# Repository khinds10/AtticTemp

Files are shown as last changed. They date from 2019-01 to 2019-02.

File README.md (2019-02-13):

# AtticTemp - temperature / climate logger
High tolerance temperature gauge and climate logger for your attic or other outdoor structures

#### Flashing RaspberriPi Hard Disk / Install Required Software (Using Ubuntu Linux)

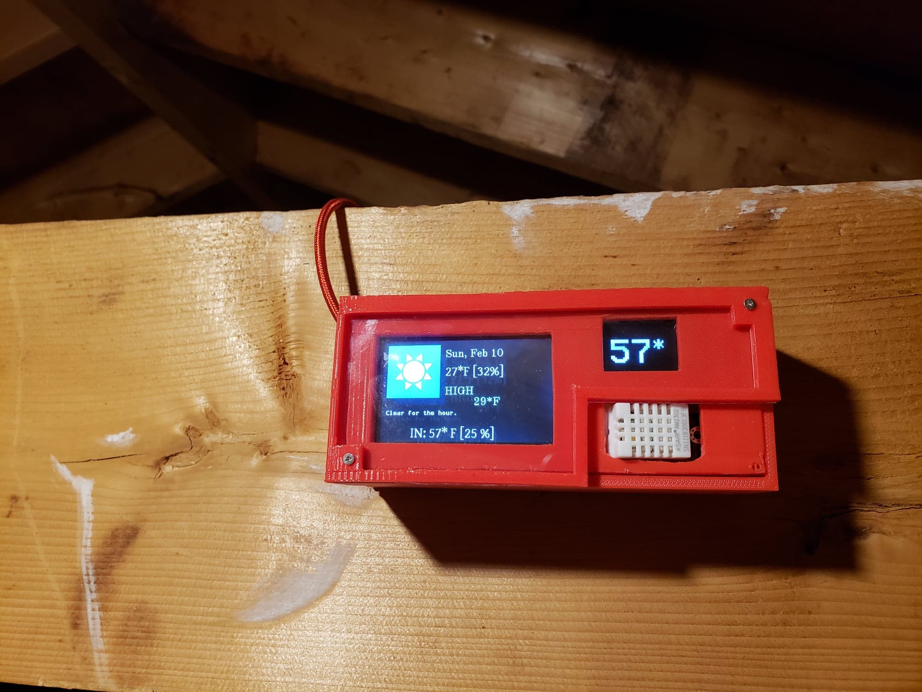
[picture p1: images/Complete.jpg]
Completed


Download "RASPBIAN JESSIE LITE"
https://www.raspberrypi.org/downloads/raspbian/

**Create your new hard disk for DashboardPI**
>Insert the microSD to your computer via USB adapter and create the disk image using the `dd` command
>
> Locate your inserted microSD card via the `df -h` command, unmount it and create the disk image with the disk copy `dd` command
>
> $ `df -h`
> */dev/sdb1       7.4G   32K  7.4G   1% /media/XXX/1234-5678*
>
> $ `umount /dev/sdb1`
>
> **Caution: be sure the command is completely accurate, you can damage other disks with this command**
>
> *if=location of RASPBIAN JESSIE LITE image file*
> *of=location of your microSD card*
>
> $ `sudo dd bs=4M if=/path/to/raspbian-jessie-lite.img of=/dev/sdb`
> *(note: in this case, it's /dev/sdb, /dev/sdb1 was an existing factory partition on the microSD)*

**Setting up your RaspberriPi**

*Insert your new microSD card to the raspberrypi and power it on with a monitor connected to the HDMI port*

Login
> user: **pi**
> pass: **raspberry**

Change your account password for security
>`sudo passwd pi`

Enable RaspberriPi Advanced Options
>`sudo raspi-config`

Choose:
`1 Expand File System`

`9 Advanced Options`
>`A2 Hostname`
>*change it to "AtticTemp"*
>
>`A4 SSH`
>*Enable SSH Server*
>
>`A7 I2C`
>*Enable i2c interface*

**Enable the English/US Keyboard**

>`sudo nano /etc/default/keyboard`

> Change the following line:
>`XKBLAYOUT="us"`

**Reboot PI for Keyboard layout changes / file system resizing to take effect**
>$ `sudo shutdown -r now`

**Auto-Connect to your WiFi**

>`sudo nano /etc/wpa_supplicant/wpa_supplicant.conf`

Add the following lines to have your raspberrypi automatically connect to your home WiFi
*(if your wireless network is named "linksys" for example, in the following example)*

	network={
	   ssid="linksys"
	   psk="WIRELESS PASSWORD HERE"
	}

**Reboot PI to connect to WiFi network**

>$ `sudo shutdown -r now`
>
>Now that your PI is finally on the local network, you can login remotely to it via SSH.
>But first you need to get the IP address it currently has.
>
>$ `ifconfig`
>*Look for "inet addr: 192.168.XXX.XXX" in the following command's output for your PI's IP Address*

**Go to another machine and login to your raspberrypi via ssh**

> $ `ssh pi@192.168.XXX.XXX`

**Start Installing required packages**

>$ `sudo apt-get update`
>
>$ `sudo apt-get upgrade`
>
>$ `sudo apt-get install vim git python-requests python-smbus i2c-tools python-imaging python-smbus build-essential python-dev rpi.gpio python3 python3-pip libi2c-dev`

**Update local timezone settings**

>$ `sudo dpkg-reconfigure tzdata`

> select your timezone using the interface

**Setup the simple directory `l` command [optional]**

>$ `vi ~/.bashrc`
>
>*add the following line:*
>
>$ `alias l='ls -lh'`
>
>$ `source ~/.bashrc`

**Fix VIM default syntax highlighting [optional]**

>$ `sudo vi /etc/vim/vimrc`
>
>uncomment the following line:
>
>_syntax on_

**Clone Project repository**

>$ `cd ~`
>
>$ `git clone https://github.com/khinds10/AtticTemp.git`

**DHT22 Install**

>$ `cd ~`
>
>$ `git clone https://github.com/adafruit/Adafruit_Python_DHT.git`
>
>$ `cd Adafruit_Python_DHT/`
>
>$ `sudo python setup.py install`
>
>$ `sudo python ez_setup.py`
>
>$ `cd examples/`
>
>$ `vi simpletest.py`
>

Change the following line:
> sensor = Adafruit_DHT.DHT22

Comment the line out
> pin = 'P8_11'

Uncomment the line and change the pin number to 16
> pin = 18

Run the test

`python simpletest.py`

> You should see a metric reading of Temp and Humidity displayed on the command line.

**SSD1306 Install**

Extract drivers/SSD1306.zip to the project folder

Install the Driver

> cd ssd1306/
>$ sudo python setup.py install

Confirm your device registers, usually it's \0x3c on the i2c bus

>$ sudo i2cdetect -y 1

         0  1  2  3  4  5  6  7  8  9  a  b  c  d  e  f
    00:          -- -- -- -- -- -- -- -- -- -- -- -- -- 
    10: -- -- -- -- -- -- -- -- -- -- -- -- -- -- -- -- 
    20: -- -- -- -- -- -- -- -- -- -- -- -- -- -- -- -- 
    30: -- -- -- -- -- -- -- -- -- -- -- -- 3c -- -- -- 
    40: -- -- -- -- -- -- -- -- -- -- -- -- -- -- -- -- 
    50: -- -- -- -- -- -- -- -- -- -- -- -- -- -- -- -- 
    60: -- -- -- -- -- -- -- -- -- -- -- -- -- -- -- -- 
    70: -- -- -- -- -- -- -- --

Run the demo to confirm your display is in working order

>$ cd examples/
>$ python demo.py 

## Supplies Needed

RaspberriPi Zero

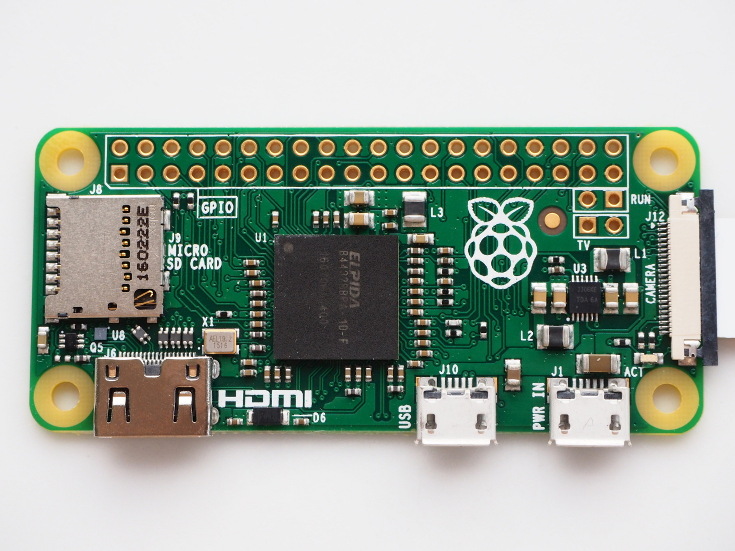
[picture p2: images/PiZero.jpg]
RaspberriPi Zero


DHT22 temperature-humidity sensor

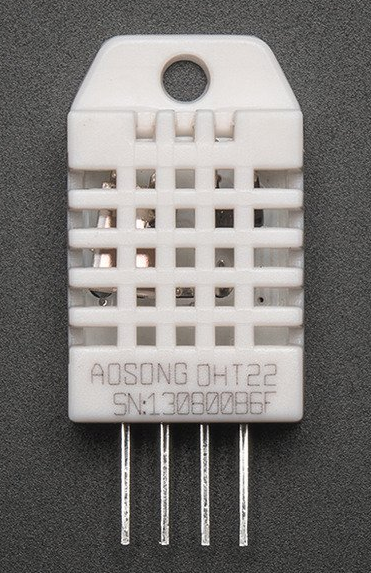
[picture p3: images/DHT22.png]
DHT22


0.96" I2C IIC SPI Serial 12864 OLED LCD LED White Display Module 

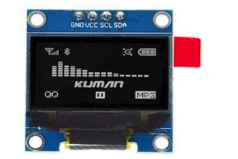
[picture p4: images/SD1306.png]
SD1306


2.4" 400x240 16:9 Serial:UART/I2C/SPI TFT Touchscreen Display 

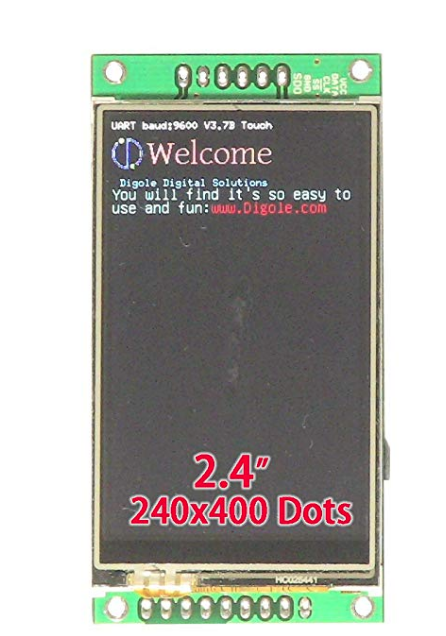
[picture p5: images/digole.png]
Digole Display


## Wire the device

**SSD1306 Display**

> GND -> GND
>
> DATA -> SDA
>
> CLK -> SCL
>
> VCC -> 3V

**Digole Display**

> GND -> GND
>
> DATA -> SDA
>
> CLK -> SCL
>
> VCC -> 3V

**DHT22 Humidistat**

> VCC -> 5V
>
> GND -> GND
>
> DATA -> GPIO 18 / PIN 12
>

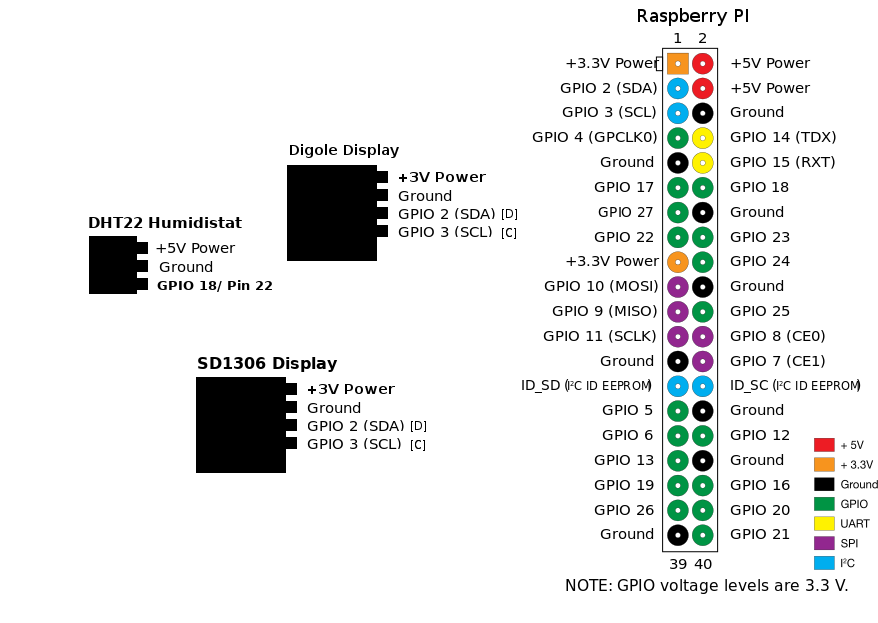
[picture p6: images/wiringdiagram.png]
Pi Wiring Diagram


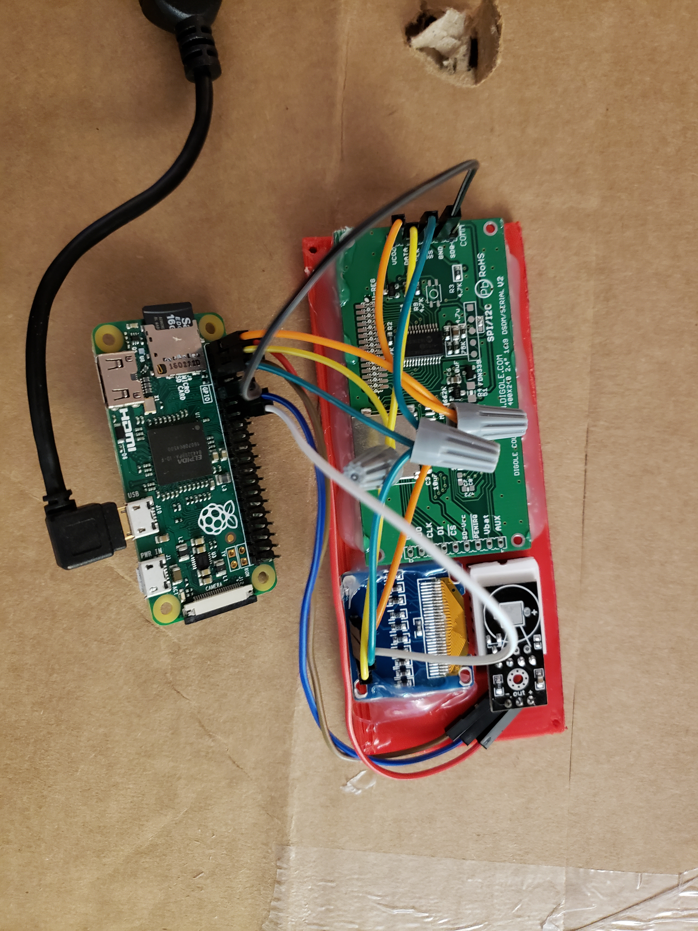
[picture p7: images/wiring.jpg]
Pi Wiring


## Build the device

Cut Plexiglass to fit the front of the device under the 3D printed frame

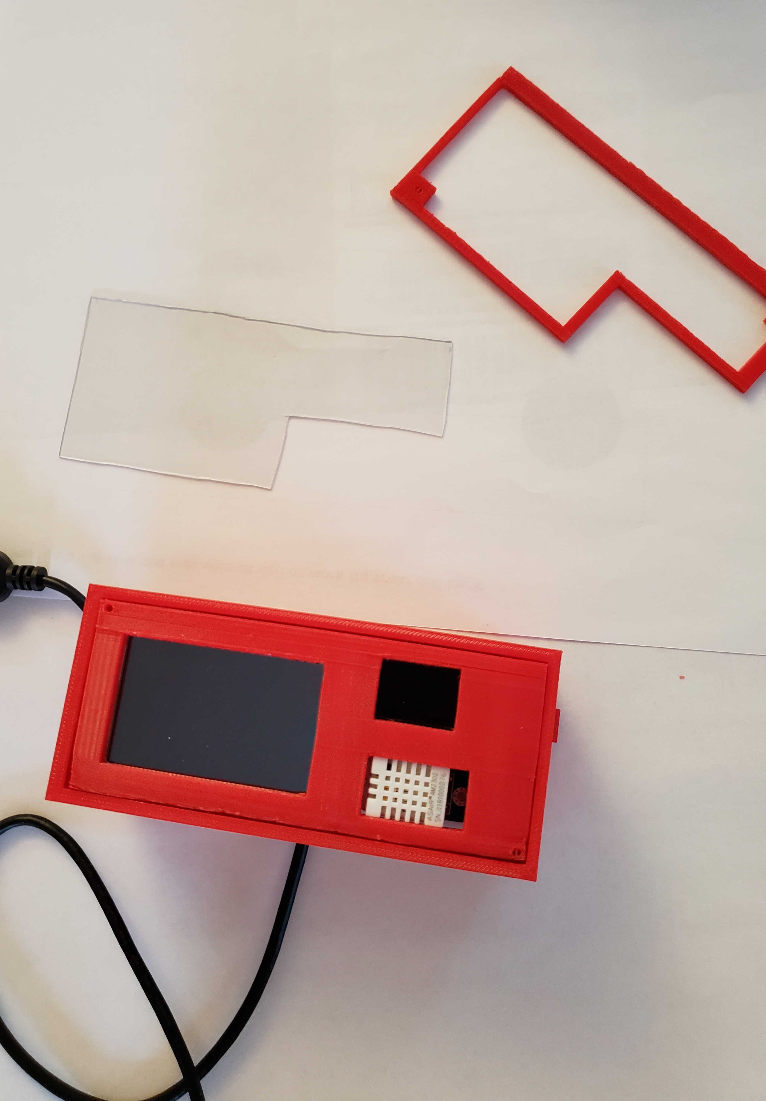
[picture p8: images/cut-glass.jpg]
Cut Plexiglass


Mount the glass with screws through the 3D printed frame

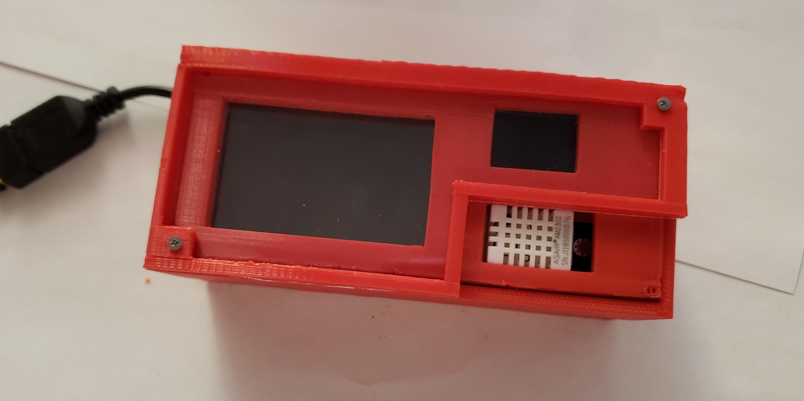
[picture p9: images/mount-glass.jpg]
Mount Glass


Hot Glue Components against the front panel

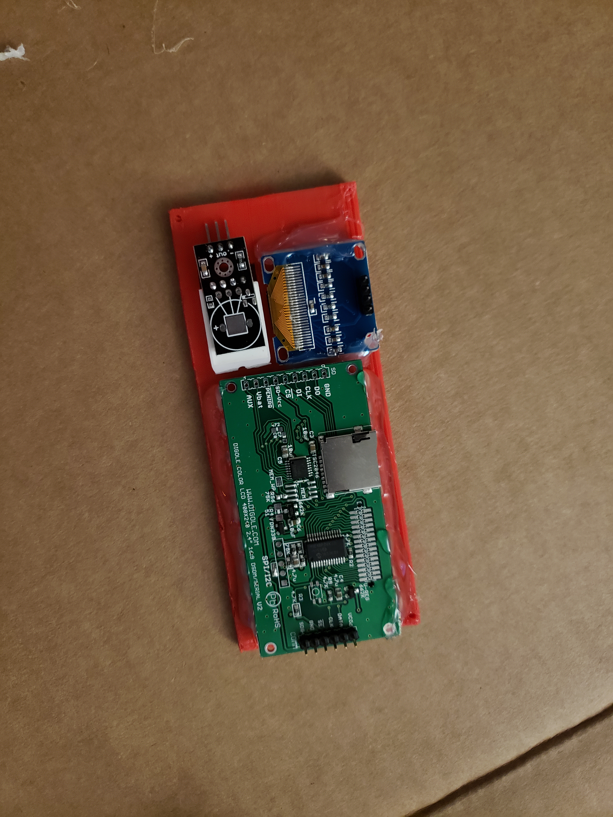
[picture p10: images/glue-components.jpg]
Hot Glue


Wire Unit inside

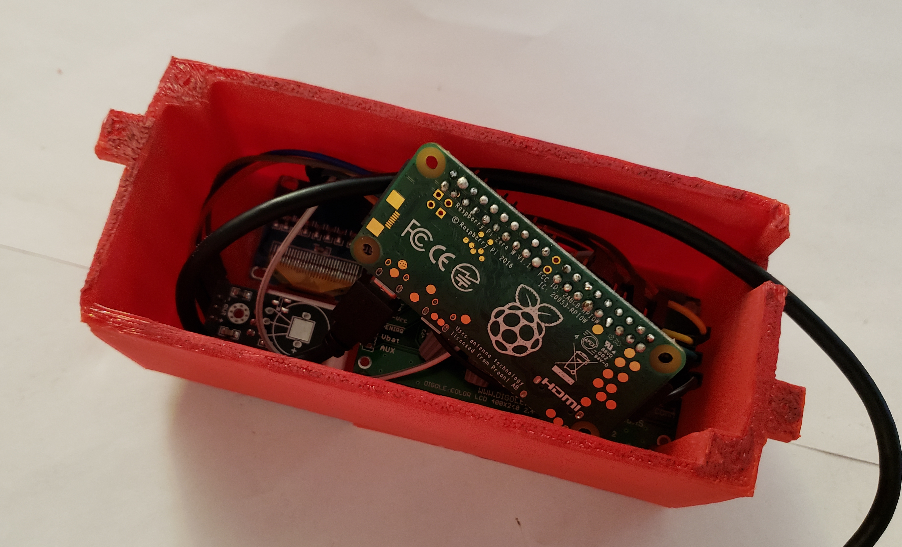
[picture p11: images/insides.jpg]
Inside Unit


Mount the back and it should be ready to go

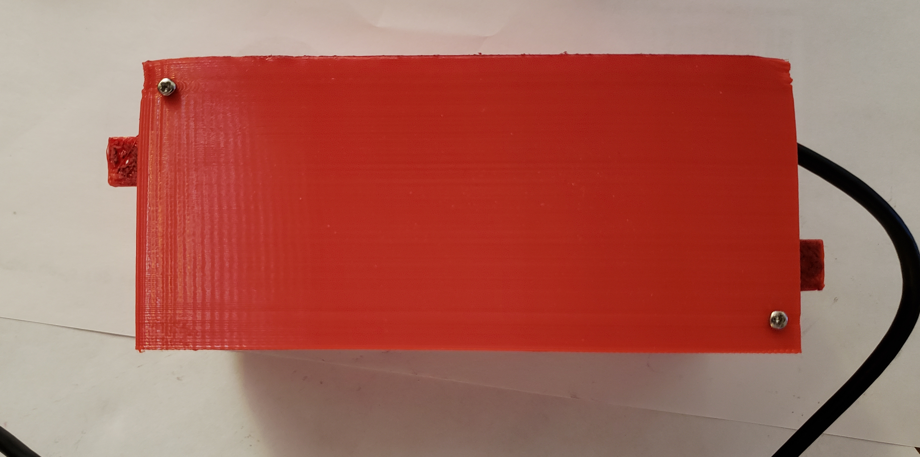
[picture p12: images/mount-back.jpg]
Mount Back


## Configure Application to run correctly in settings.py config file

Find the file `settings.py` and adjust to your current settings

> \# forecast.io API key for local weather information
>
> weatherAPIURL = 'https://api.forecast.io/forecast/'
>
> weatherAPIKey = 'YOUR API KEY FOR FORECAST.IO'
> 
> \# optional for running the remote temp/humidity logger
>
> deviceLoggerAPI = 'mydevicelogger.com'
>
> \# search google to get the Latitude/Longitude for your home location
>
> latitude = 41.4552578
>
> longitude = -72.1665444
>

## Setup Scheduled Scripts

>$ `crontab -e`

Add the following lines:

`*/7 * * * * python /home/pi/AtticTemp/displays.py`

## OPTIONAL: Temp Logger to API script each 10 minutes

>$ `crontab -e`

Add the following lines:

`*/10 * * * * python /home/pi/EnvironmentClock/temp-check.py`

## OPTIONAL: Creating your own weather images to render on the display

Upload your own 128x128 file to the following URL:

http://www.digole.com/tools/PicturetoC_Hex_converter.php 

Choose your image file to upload, add what size you want it to be on the screen (Width/Height)

Select "256 Color for Color OLED/LCD(1 byte/pixel)" in the "Used for" dropdown

Obtain the hex output.

Add the hex output to a display/build/ header (.h) file, use the other ones as guides for syntax.

Include the new file in the digole.c file 
`#include "myimage.h`

Include a new command line hook to your image file in the.
_Note: the command below is saying draw your image at position 10 pixels over 10  pixels down. You can change it to different X,Y coordinates, you can also change the values 128,128 to whatever size your new image actually is._

`} else if (strcmp(digoleCommand, "myimage") == 0) {`
    `drawBitmap256(10, 10, 128, 128, &myimageVariableHere,0);  // myimageVariableHere is defined in your (.h) file`
`}`

Now rebuild (ignore the errors) below to have your new image render with the following command.
>$ `./digole myimage`

**Re-Building [Included] Digole Display Driver for your optional changes**

>$ `cd display/build`

>$ `gcc digole.c`

>$ `mv a.out ../../digole`

>$ `chmod +x ../../digole`

# FINISHED!

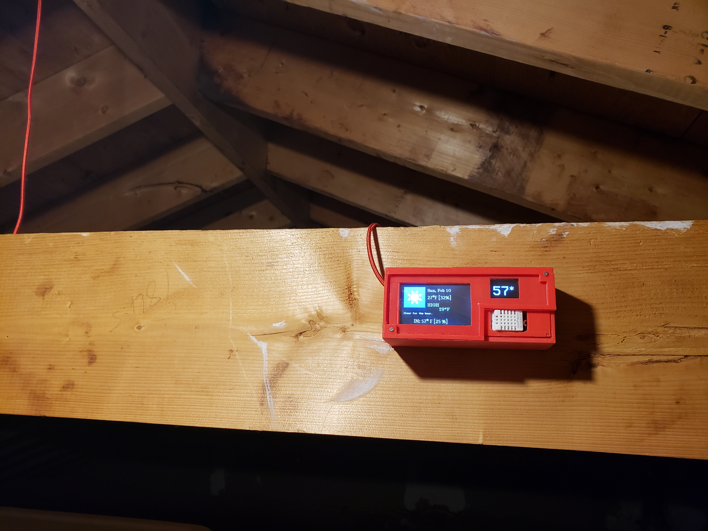
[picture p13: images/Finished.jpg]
Finished


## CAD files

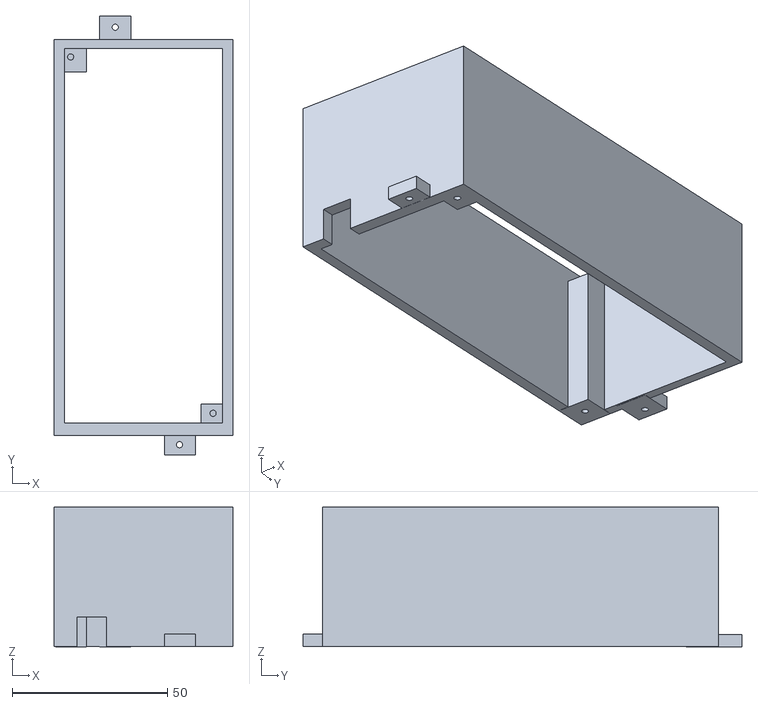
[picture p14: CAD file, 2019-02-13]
enclosure/main-box.stl
57.5 x 141.4 x 45.1

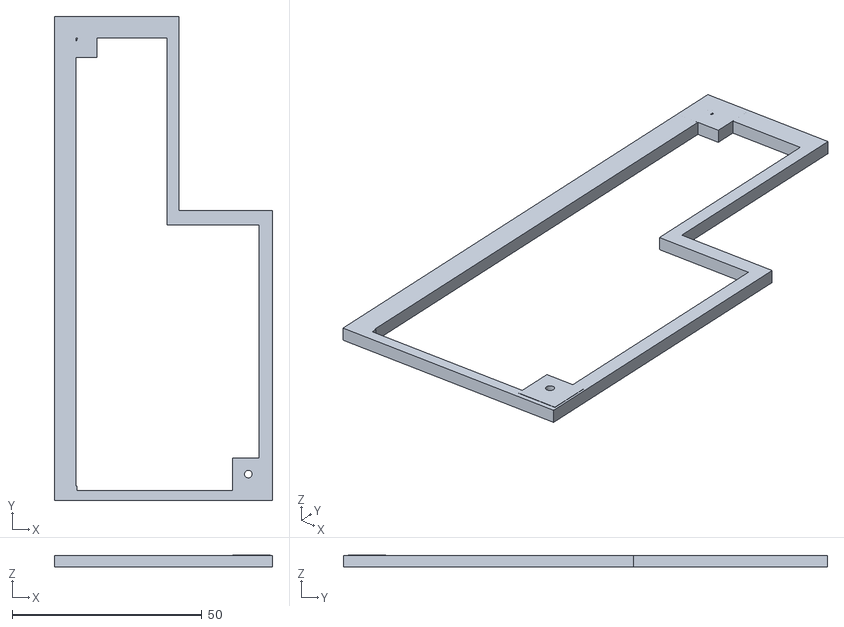
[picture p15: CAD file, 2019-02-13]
enclosure/glass-panel.stl
57.5 x 127.5 x 3.07

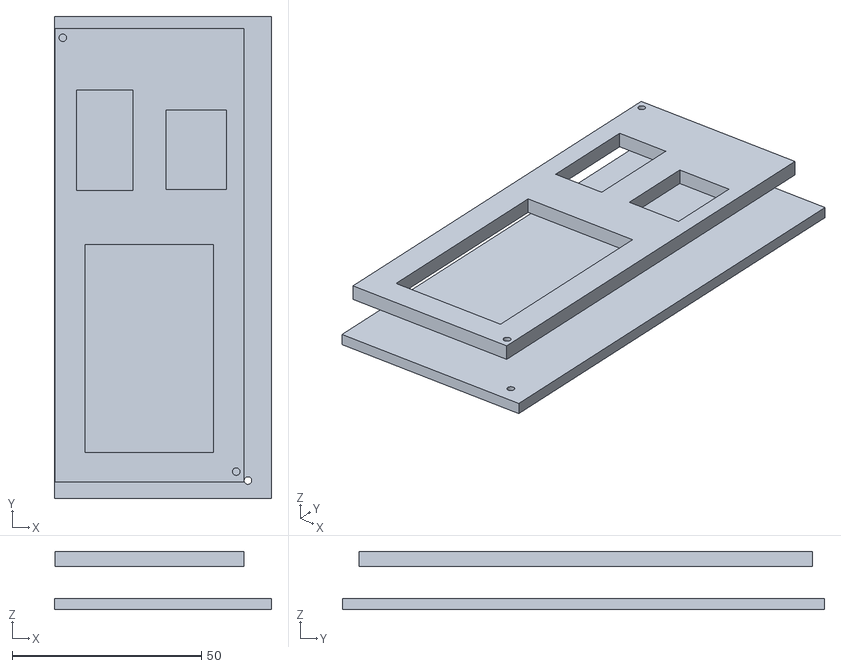
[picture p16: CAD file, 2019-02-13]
enclosure/top-bottom.stl
57.5 x 127.5 x 15.4

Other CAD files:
enclosure/enclosure-final.blend
enclosure/enclosure.blend

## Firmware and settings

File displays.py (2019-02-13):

#!/usr/bin/python
# Kevin Hinds http://www.kevinhinds.com
# License: GPL 2.0
import datetime as dt
import time, json, string, cgi, subprocess, json
import settings as settings
import Adafruit_DHT
from oled.device import ssd1306
from oled.render import canvas
from PIL import ImageFont

# mono 8 bit font
font = ImageFont.truetype('/home/pi/AtticTemp/fonts/vcr.ttf', 50)
device = ssd1306(port=1, address=0x3C)

## Raspberry Pi with DHT22 sensor - connected to GPIO18 / Pin 12
sensor = Adafruit_DHT.DHT22
pin = 18

# get current date and time
date=dt.datetime.now()

# get 10 readings and average, in case the humidistat is inaccurate
count, readingCount, avgTemperature, avgHumidity = [ 0, 0, 0, 0 ]
while (count < 10):    
    humidity, temperature = Adafruit_DHT.read_retry(sensor, pin)
    if humidity is not None and temperature is not None:
        avgTemperature = avgTemperature + temperature
        avgHumidity = avgHumidity + humidity
        readingCount = readingCount + 1                
    count = count + 1
avgTemperature = avgTemperature / readingCount
insideTemperature = int(avgTemperature * 9/5 + 32)
avgHumidity = avgHumidity / readingCount
insideHumidity = int(avgHumidity)

# show temp on the 1306 display
with canvas(device) as draw:
    if insideTemperature > 100:
        font = ImageFont.truetype('/home/pi/AtticTemp/fonts/vcr.ttf', 50)
        draw.text((0, 10),    str(insideTemperature),  font=font, fill=255)
        font = ImageFont.truetype('/home/pi/AtticTemp/fonts/vcr.ttf', 30)
        draw.text((90, 15),    str("*"),  font=font, fill=255)
    elif insideTemperature >= 0:
        font = ImageFont.truetype('/home/pi/AtticTemp/fonts/vcr.ttf', 60)
        draw.text((0, 10),    str(insideTemperature),  font=font, fill=255)
        font = ImageFont.truetype('/home/pi/AtticTemp/fonts/vcr.ttf', 40)
        draw.text((70, 15),    str("*"),  font=font, fill=255)       
    else:
        font = ImageFont.truetype('/home/pi/AtticTemp/fonts/vcr.ttf', 50)
        draw.text((0, 10),    str(insideTemperature),  font=font, fill=255)
        font = ImageFont.truetype('/home/pi/AtticTemp/fonts/vcr.ttf', 30)
        draw.text((90, 15),    str("*"),  font=font, fill=255)

# get current forecast from location
weatherInfo = json.loads(subprocess.check_output(['curl', settings.weatherAPIURL]))
currentConditions = weatherInfo['currently']
icon = str(currentConditions['icon'])
apparentTemperature = str(int(currentConditions['apparentTemperature']))
humidity = str(int(currentConditions['humidity'] * 100))
windSpeed = str(int(currentConditions['windSpeed']))
cloudCover = str(int(currentConditions['cloudCover'] * 100))
precipProbability = str(int(currentConditions['precipProbability'] * 100))

# minutely conditions, limit the characters to 30 in the summary
minutelyConditions = weatherInfo['minutely']
summary = str(minutelyConditions['summary'])
summary = (summary[:27] + '...') if len(summary) > 29 else summary

# conditions for the day
dailyConditions = weatherInfo['daily']
dailyConditions = dailyConditions['data'][0]
apparentTemperatureMin = str(int(dailyConditions['apparentTemperatureMin']))
apparentTemperatureMax = str(int(dailyConditions['apparentTemperatureMax']))

# clear and setup display to show basic info
subprocess.call(["/home/pi/AtticTemp/digole", "clear"])
subprocess.call(["/home/pi/AtticTemp/digole", "setRot90"])
subprocess.call(["/home/pi/AtticTemp/digole", icon])
subprocess.call(["/home/pi/AtticTemp/digole", "setFont", "18"])
subprocess.call(["/home/pi/AtticTemp/digole", "setColor", "255"])
subprocess.call(["/home/pi/AtticTemp/digole", "printxy_abs", "10", "178", summary])
subprocess.call(["/home/pi/AtticTemp/digole", "setFont", "51"])
subprocess.call(["/home/pi/AtticTemp/digole", "printxy_abs", "150", "40", date.strftime('%a, %b %d')])

# print the min daily temp in the evening and night, print the day max temp in the morning and daytime
if dt.datetime.now().hour > 16 or dt.datetime.now().hour < 6:
    subprocess.call(["/home/pi/AtticTemp/digole", "setColor", "223"])
    subprocess.call(["/home/pi/AtticTemp/digole", "printxy_abs", "150", "130", "LOW\n" + apparentTemperatureMin + '*F'])
else:
    subprocess.call(["/home/pi/AtticTemp/digole", "setColor", "222"])
    subprocess.call(["/home/pi/AtticTemp/digole", "printxy_abs", "150", "130", "HIGH\n" + apparentTemperatureMax + '*F'])

# show indoor / outdoor temp
subprocess.call(["/home/pi/AtticTemp/digole", "setFont", "120"])

subprocess.call(["/home/pi/AtticTemp/digole", "setColor", "255"])
subprocess.call(["/home/pi/AtticTemp/digole", "printxy_abs", "150", "85", apparentTemperature + "*F [" + humidity + "%]"])

subprocess.call(["/home/pi/AtticTemp/digole", "setColor", "250"])
subprocess.call(["/home/pi/AtticTemp/digole", "printxy_abs", "70", "230", "IN: " + str(insideTemperature) + "* F [" + str(insideHumidity) + " %]"])

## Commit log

2019-02-02 full paths for crons, fixed temp marker
    [displays.py]
2019-02-13 added construction and 3D print enclosure files
    [enclosure-final.blend, enclosure.blend, glass-panel.stl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]
2019-02-13 added wiring diagram
